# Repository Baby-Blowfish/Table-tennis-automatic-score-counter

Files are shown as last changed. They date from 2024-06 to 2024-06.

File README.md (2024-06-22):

# Table-tennis-automatic-score-counter (2022.06 ~ 2023.12)

## 1. 개발 배경 및 목적 :
    - 지역사회의 스포츠 활성화를 위해 체육학과 학우들과 탁구장을 창업 및 무인으로 탁구장을 운영할 수 있는 탁구자동점수계수 시스템을 구축

## 2. 프로젝트 개요 :

    - 안동형 일자리센터에서 창업 첫걸음 지원사업으로 선정되어 1300만 원을 지원받아 Lead All 탁구장 창업 및 1년간 운영
    - 자동점수 계수기 개발하고 시제품을 1년간 탁구장 배치하여 소비자들의 피드백을 바탕으로 특허 출원
    - 학생 창업 유망팀 300 경진대회 성장 트랙에서 "3차원 동작분석을 통한 탁구선수 경기력 향상 솔루션"으로 모의 투자 대회에서
    2300만원 투자 유치 달성 및 교육부장관 인증서 수상

## 3. 프로젝트 내 역할 
    - 경기자가 PLAYER BOARD의 UP & DOWN 스위치를 조작하여 Bluetooth 통신으로 SCORE BOARD에 점수 제어값을 송신하
    는 기능 개발
    - SCORE BOARD는 PLAYER BOARD의 제어값을 수신받아 점수를 계수하고 결과를 7-segment로 표시하는 기능 개발
    - 스피커로 경기 결과 및 타이머로 경과된 시간을 출력하여 소비자에게 지불할 금액 알림 기능 개발
    - SCORE BOARD에 스마트폰 거치대와 USB-C 타입 충전 기능 개발
    - Kinect camera와 motion capture 기능으로탁구선수의 경기력 향상을 위한 3차원 동작 분석 시스템 설계

## 4. 성과
    - 안동시 창업 첫걸음 사업 (탁구 자동점수 계수기 개발 및 특허 출원), 학생 창업 유망팀 300 경진대회 성장 트랙

##

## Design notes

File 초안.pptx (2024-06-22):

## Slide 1

| 시스템 구성도

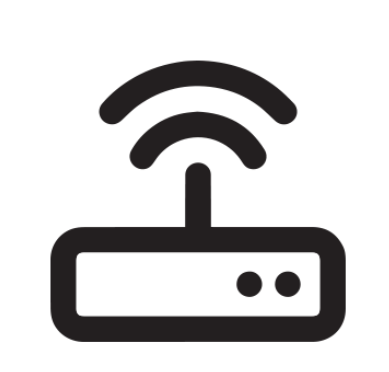
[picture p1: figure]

SCORE BOARD

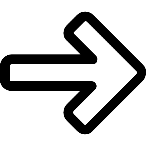
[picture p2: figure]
오른쪽 화살표 무료 아이콘
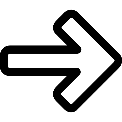
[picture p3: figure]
오른쪽 화살표 무료 아이콘

PLAYER BOARD

PLAYER BOARD

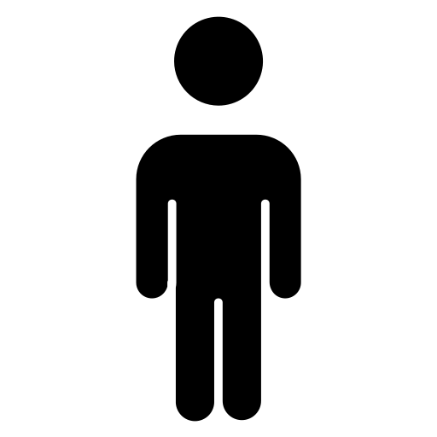
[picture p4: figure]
Man free icon
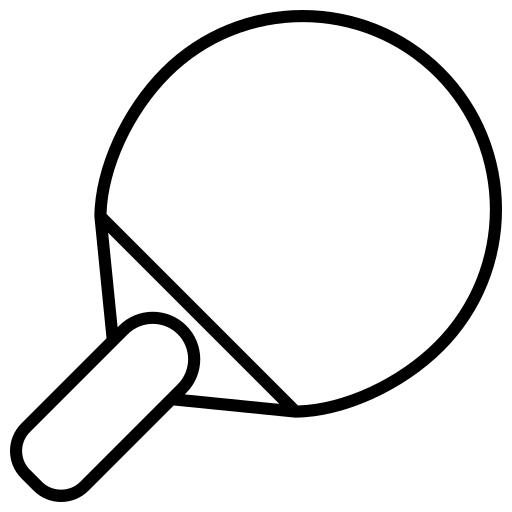
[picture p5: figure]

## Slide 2

| 시스템 구성도

PLAYER BOARD

점수 UP/DOWN 스위치 4개
RESET 스위치 1개
타이머 시작/정지/리셋 스위치 1개

적외선 수신부

점수 7-segment 4개
세트 7-segment 4개
타이머 7-segment 4개

SCORE BOARD

SCORE BOARD

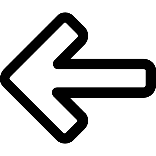
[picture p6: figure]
오른쪽 화살표 무료 아이콘

적외선 통신

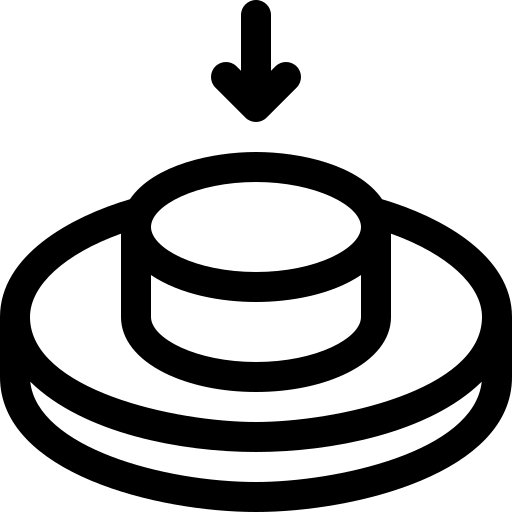
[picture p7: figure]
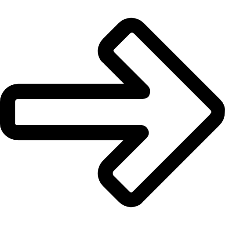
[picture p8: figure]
오른쪽 화살표 무료 아이콘

PHONE CHARGE

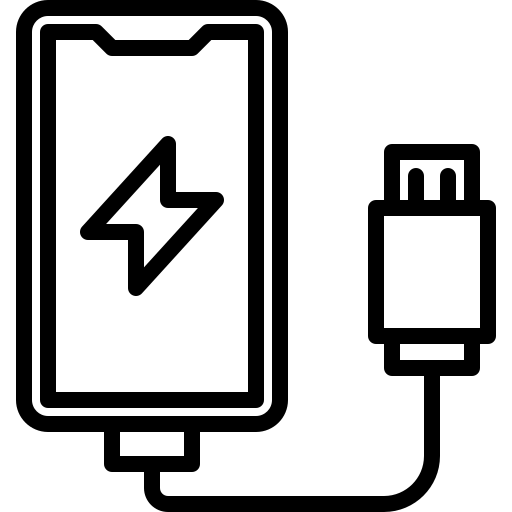
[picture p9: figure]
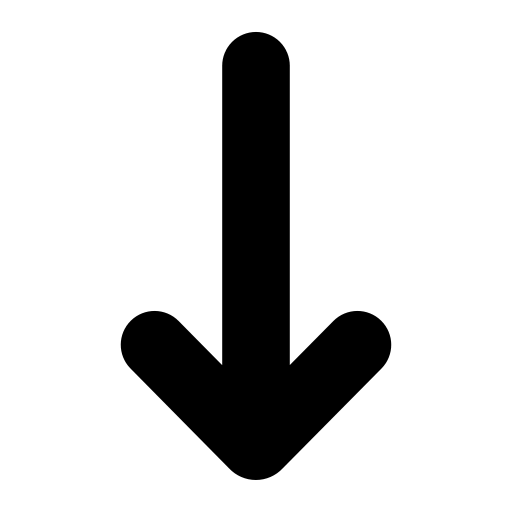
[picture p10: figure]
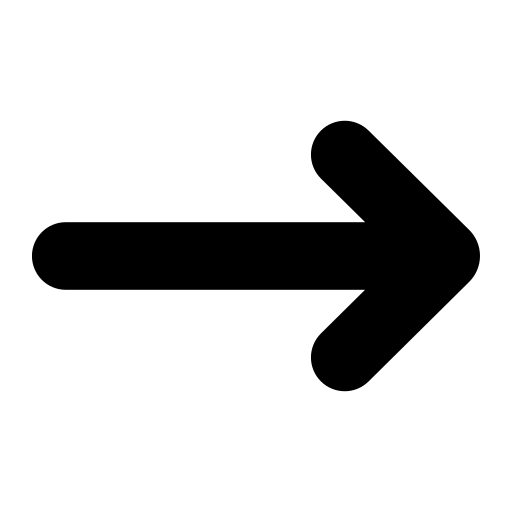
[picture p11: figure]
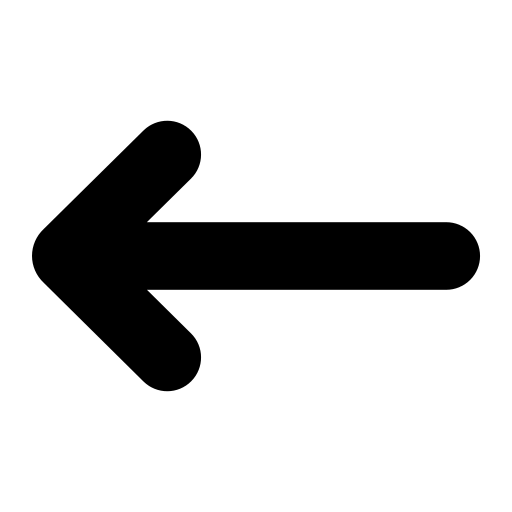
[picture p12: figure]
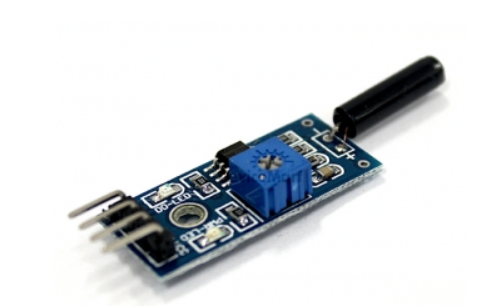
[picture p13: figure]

진동센서 모듈

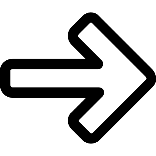
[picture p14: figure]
오른쪽 화살표 무료 아이콘
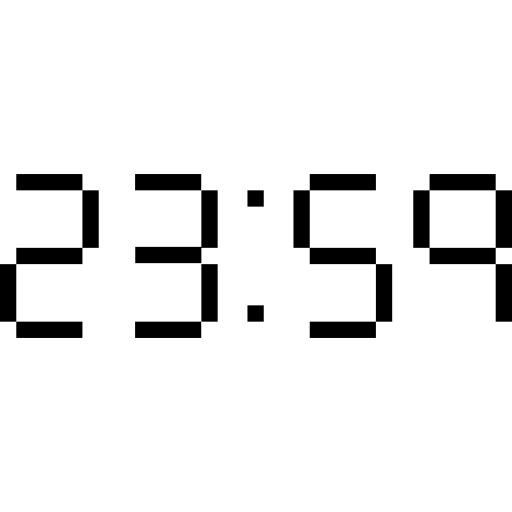
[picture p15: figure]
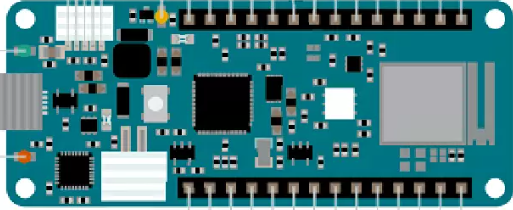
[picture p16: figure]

무선인터넷을 이용해 서버에 데이터 전송

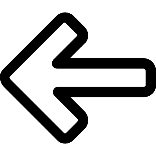
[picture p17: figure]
오른쪽 화살표 무료 아이콘
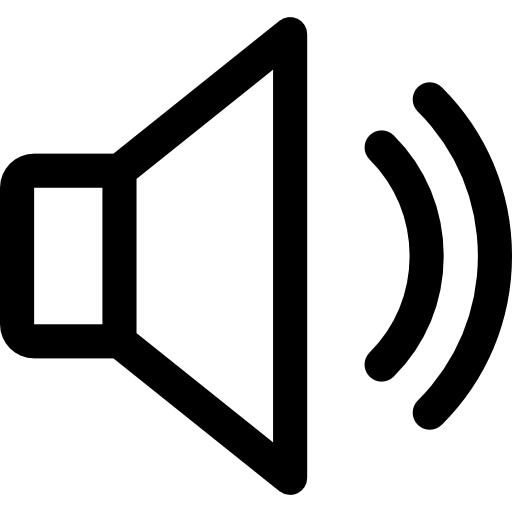
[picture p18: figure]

스피커

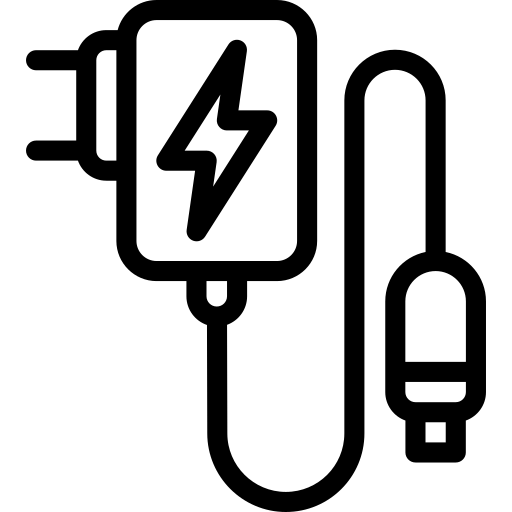
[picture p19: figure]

220V 충전기

MKR wifi 1010

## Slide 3

| 시스템 구성도

PLAYER BOARD

점수 UP/DOWN 스위치 2개

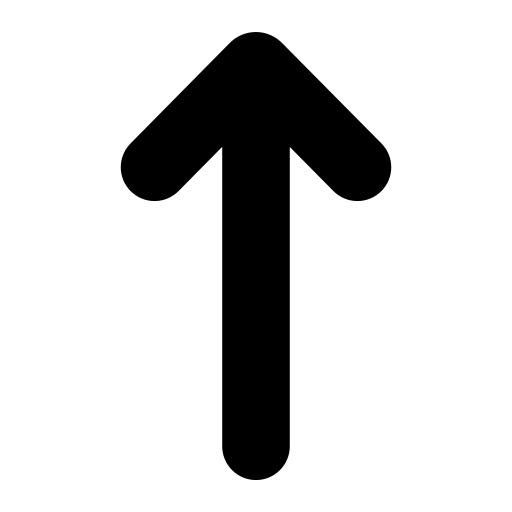
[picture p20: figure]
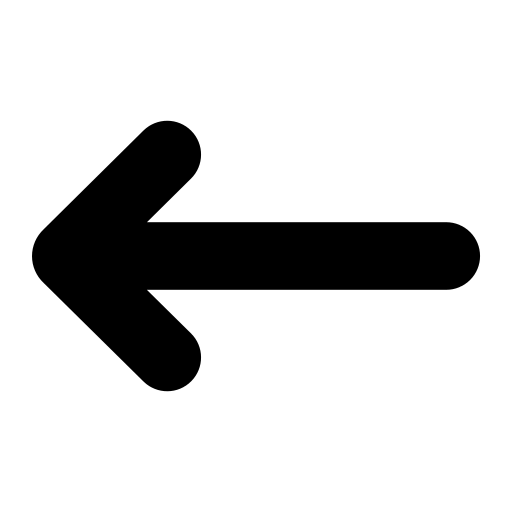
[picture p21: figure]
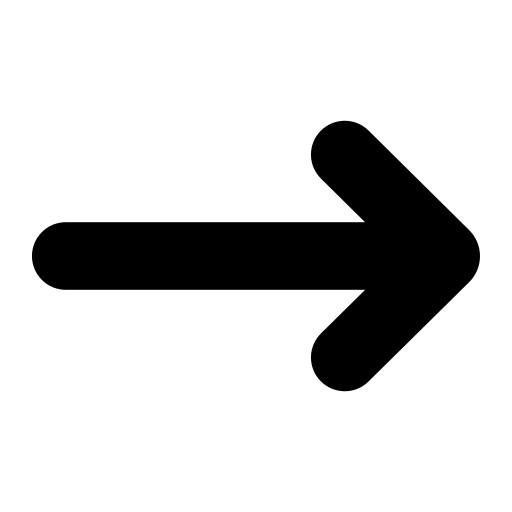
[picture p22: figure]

적외선 송신부

SCORE BOARD

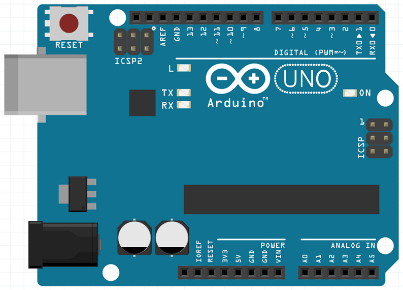
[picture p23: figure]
Arduino 시작하기 | STEM with

Arduino UNO

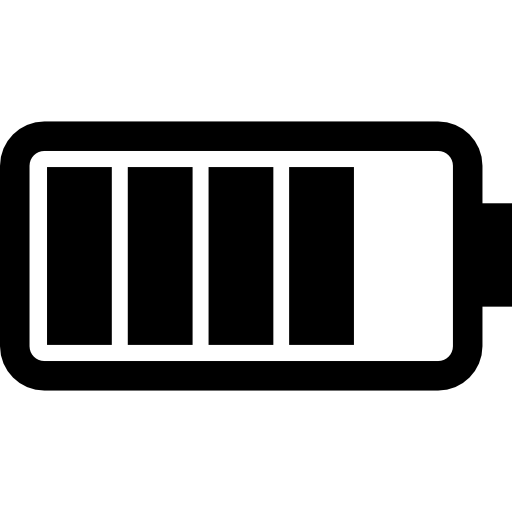
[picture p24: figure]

9V 건전지

적외선 통신

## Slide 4

| SCORE BOARD 전면

세트 스코어 출력
숫자 전광판

점수초기화 버튼

점수 추가/제거 버튼

시간 시작/정지/리셋 버튼

시간 숫자 전광판

점수 출력 숫자 전광판

적외선 송신부

스피커

휴대폰 거치대 및 충전용 USB 단자

음량 조절 단자

진동 센서 연결 포트

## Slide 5

| SCORE BOARD 측면

여닫을 수 있는 거치대

전원 공급 DC 잭 단자

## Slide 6

| PLEAER BOARD 하면/측면

점수 추가/제거 버튼

부착용 벨크로

건전지 교체 뚜껑

적외선 수신부

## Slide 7

| FND PCB

FND 큰거 작은거를 둘 다 호환 가능.
홀더는 설명을 위해 넣음. 실제로는 바로 납땜할거임.
ICD 케이블 홀더를 먼저 납땜 후 PCB를 납땜해야 함.

FND 홀

FND 큰거

FND 작은거

앞

옆

뒤

PCB 고정용
홀, 3파이

10핀 ICD 케이블 홀더

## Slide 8

| MAIN PCB

MAIN PCB
가로 : 260
세로 : 85

sw 8핀 커넥터

dfplayer
mini

가로로
타이머, 스피커,
USB 2개, IR센서
진동센서
5V pin

FND PCB
가로 : 40
세로 : 163

만능기판
12 * 25

SCORE_LEFT

아두이노
MKR 1010 wifi

SET_LEFT

전원
커넥터

SET_RIGHT

SCORE_RIGHT

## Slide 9

| 전체 PCB

FND 큰거 작은거를 둘 다 호환 가능.

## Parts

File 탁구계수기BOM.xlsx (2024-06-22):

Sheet: 경대 BOM
순번 | 이름 | 모델 | 수량 | 규격 | 참고 | 비고
1 | IC | NE555P | 2 | DIP8 | https://www.devicemart.co.kr/goods/view?no=1058745
2 |  | HEF4518BP | 1 | DIP16 | https://www.devicemart.co.kr/goods/view?no=1056986
3 |  | MC14051B | 2 | SO16 | https://www.devicemart.co.kr/goods/view?no=1056791
4 |  | LM324N | 1 | DIP14 | https://www.devicemart.co.kr/goods/view?no=1056784
5 |  | HEF4027BT | 1 | SO16 | https://www.devicemart.co.kr/goods/view?no=1056677
6 |  | MC14175BDR2G | 1 | SO16
7 |  | CD74HC123E | 1 | DIP16 | https://www.ti.com/lit/ds/symlink/cd74hc123.pdf
8 |  | LM7805C | 1 | TO-220
9 |  | LM7905C | 1 | TO-220
10 |  | HEF4049BT | 2 | SO16 | https://www.devicemart.co.kr/goods/view?no=14811357
11 |  | HEF4081BT | 1 | SO14 | https://www.devicemart.co.kr/goods/view?no=14566419
12 |  | HEF4011BT | 1 | SO14 | https://www.devicemart.co.kr/goods/view?no=14811434
13 |  | CD4012BE | 1 | DIP14 | https://www.devicemart.co.kr/goods/view?no=12430497
14 |  | MC14024BDG | 1 | SO14 | https://www.devicemart.co.kr/goods/view?no=14811451
15 |  | CD74HC192E | 4 | DIP16 | https://www.devicemart.co.kr/goods/view?no=14623818
16 |  | SN74LS47N | 4 | DIP16 | https://www.devicemart.co.kr/goods/view?no=28231
17 | 다이오드 | 1N5819 | 5 |  | https://www.devicemart.co.kr/goods/view?no=6514584
18 | 저항 |  |  | 칩 1608 |  | DIP도 상관없음
19 | 세라믹 콘덴서 |  |  | 칩 1608 |  | DIP도 상관없음
20 | 전해 콘덴서 |  |  | DIP
21 | 가변 저항 |  | 7 | 3296W(일자 3홀)
22 | 부저 | SM-1205C | 1 | DIP | https://www.devicemart.co.kr/goods/view?no=2736
23 | 트렌지스터 | 2n2222 | 2 | DIP
24 | 전원 | [MOLEX] 5267-03 | 1 | DIP3 | https://www.devicemart.co.kr/goods/view?no=418
25 | 서보 모터 헤더 | pin header | 1 | DIP3
26 | 서보 모터 | HS-311
27 | 7-segment | 5101ASR | 4 | DIP | https://www.devicemart.co.kr/goods/view?no=11551
28 | 텍트 스위치 |  | 1 | DIP | https://www.devicemart.co.kr/goods/view?no=1361702
29 | 4p 슬라이트 스위치 | KSD04S | 2 | 4PIN SMD | https://www.devicemart.co.kr/goods/view?no=31631

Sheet: 경대 창의회로설계 사용 IC
이름 | 제조사 | 타입 | 설명
HEF4518BP | NXP | DIP16 | Dual BCD counter
HEF4520BT | NXP | SO16 | Dual binary counter
DAC0800LCN | national semiconductor | DIP16 | 8-Bit D/A Converters | https://pdf1.alldatasheet.co.kr/datasheet-pdf/view/8300/NSC/DAC0800LCN.html
MC14543BCPG | on semi | DIP16 | BCD-to-Seven Segment Latch/Decoder/Driver for liquit crystals | https://pdf1.alldatasheet.com/datasheet-pdf/view/174233/ONSEMI/MC14543BCPG.html
MC14051B | on semi | so16 | Analog Multiplexers/Demultiplexers | pspice에서 대신 10164 사용
HEF4027BT | PHILIPS | so16 | Dual JK flip-flop | https://pdf1.alldatasheet.com/datasheet-pdf/view/17706/PHILIPS/4027.html
MC14175BDR2G | on semi | SO16 | quad type d flip-flop
74HC257D |  | SO16 | Quad 2-input multiplexer
CD74HC123E | texas instruments |  | High-Speed CMOS Logic Dual Retriggerable Monostable Multivibrators with Resets Retrigger 가능 단안정 멀티바이브레이터 | https://www.ti.com/lit/ds/symlink/cd74hc123.pdf
74LS193 |  | DIP16 | presettable BCD up/down counter | https://pdf1.alldatasheet.com/datasheet-pdf/view/5680/MOTOROLA/74LS193.html https://pdf1.alldatasheet.com/datasheet-pdf/view/51049/FAIRCHILD/74LS193.html
 |  |  |  |  |  | [표 3-23] 디멀티플렉서의 진리표
 |  |  |  |  |  | 순서 | 선택 |  | 입력 | 출력
 |  |  | cds센서는 70~5M 옴 정도가 나옴 |  |  |  | S1 | S0 | I | Y3 | Y2 | Y1 | Y0
 |  |  | 평소에는 10K옴, 적당히 어두우면 100k옴 |  |  | 1 | 0 | 0 | 1 | 0 | 0 | 0 | 1
 | 비안정 NE555 계산기 |  |  |  |  | 2 | 0 | 0 | 0 | 0 | 0 | 0 | 0
 | R1(위) | R2(아래) | C1 |  |  | 3 | 0 | 1 | 1 | 0 | 0 | 1 | 0
 | 22000 | 3400 | 1e-07 |  |  | 4 | 0 | 1 | 0 | 0 | 0 | 0 | 0
 | t H | 0.00176022 |  |  | 방법 2 | 5 | 1 | 0 | 1 | 0 | 1 | 0 | 0
 | t L | 0.00023562 |  |  |  | 6 | 1 | 0 | 0 | 0 | 0 | 0 | 0
 | period | 0.00199584 |  |  |  | 7 | 1 | 1 | 1 | 1 | 0 | 0 | 0
 | frequency | 501.0421677 |  |  |  | 8 | 1 | 1 | 0 | 0 | 0 | 0 | 0
 | 비안정 NE555 계산
 | R1(위) | R2(아래) | C1
 | 370000 | 400 | 0.00022
 | t H | 56.471184
 | t L | 0.060984
 | period | 56.532168 | 초
 | frequency | 0.01768904387
 | CD4024 출력
 | 분주비 64 | 60.3009792 | 분
 | 단안정 NE555 계산기
 | R | C
 | 21000 | 1e-07
 | t H | 0.00231
 | 74HC123 계산기
 | 콘덴서 | 저항1
 | 1e-07 | 55000
 | pulse 길이 | 0.002475
 | 콘덴서 | 저항2
 | 1e-07 | 43000
 | pulse 길이 | 0.001935
 | 콘덴서 | 저항3
 | 1e-07 | 34000
 | pulse 길이 | 0.00153
 | 콘덴서 | 저항4
 | 1e-07 | 25000
 | pulse 길이 | 0.001125
 | 콘덴서 | 저항5
 | 1e-07 | 16000
 | pulse 길이 | 0.00072

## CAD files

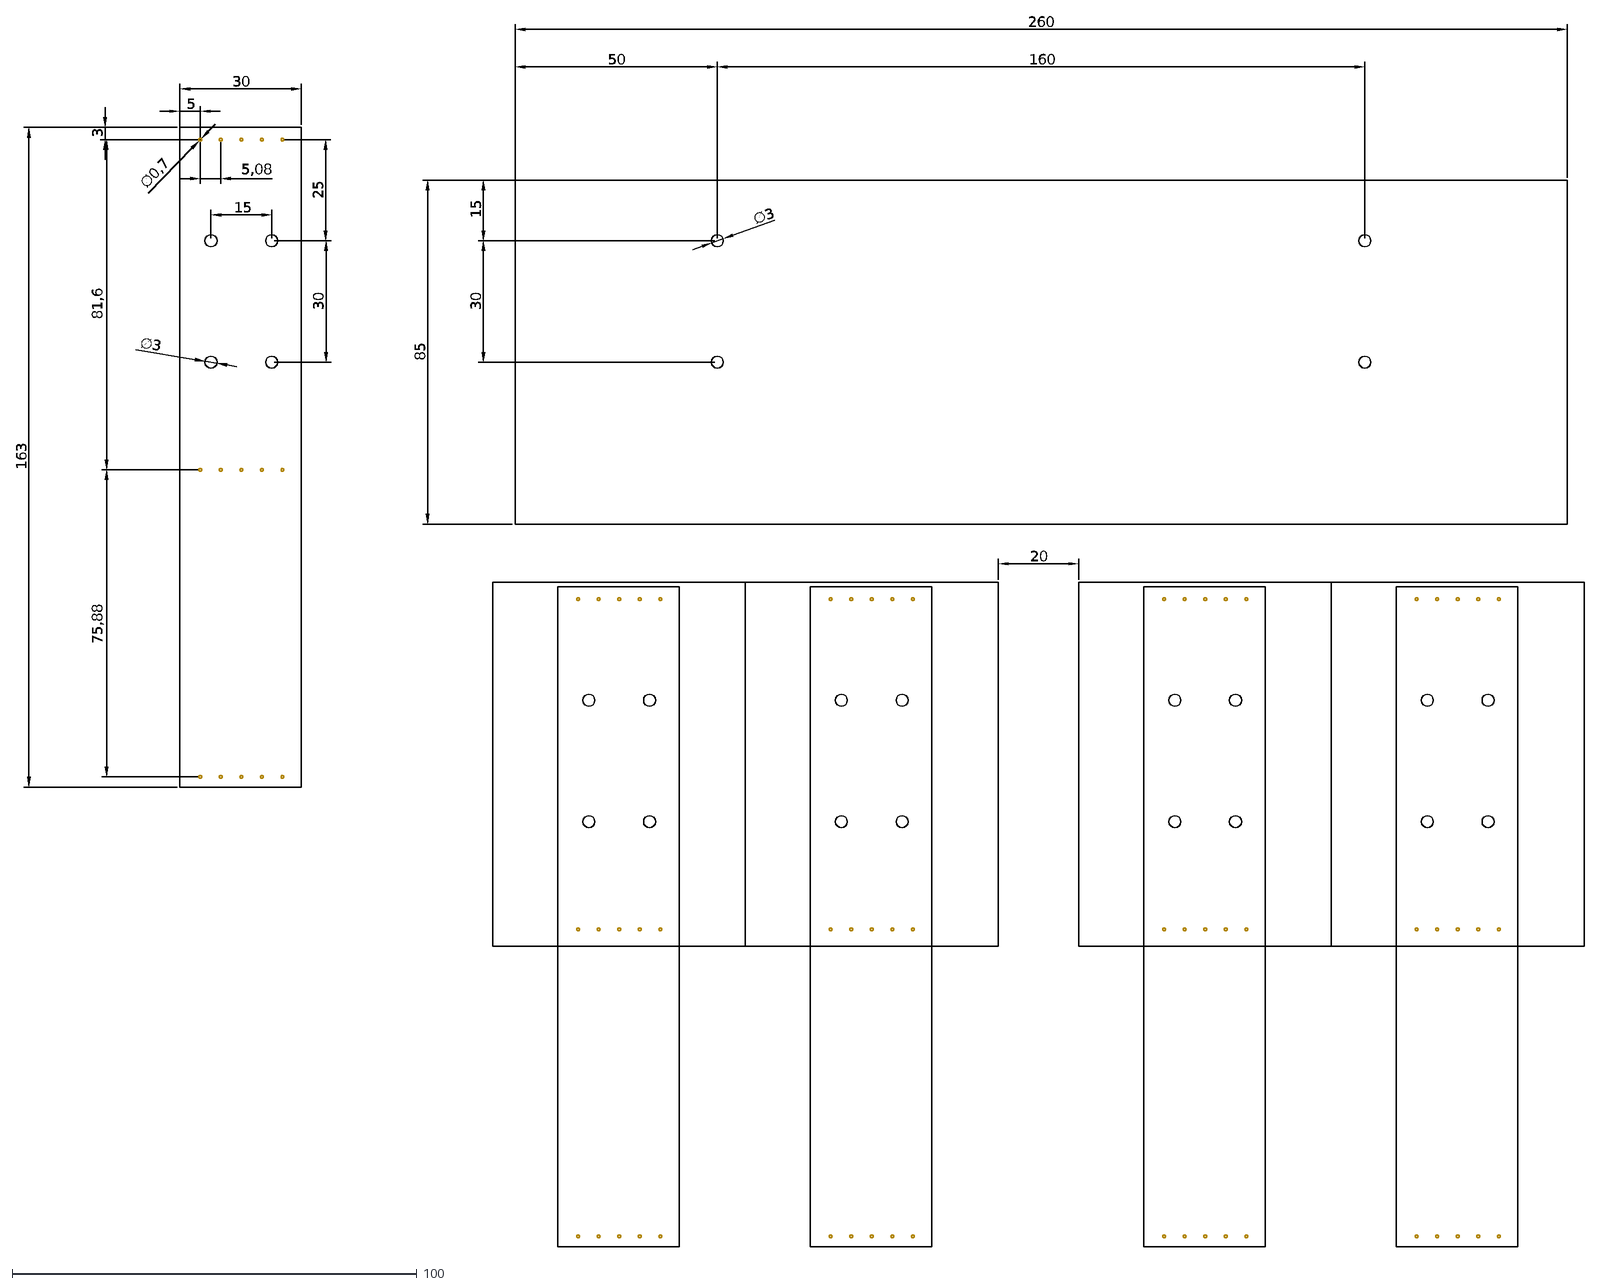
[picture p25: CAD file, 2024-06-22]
ping_pong.dxf
30
5
∅0,7
5,08
81,6
75,88
3
15
25
∅3
20
160
50
163
260
85

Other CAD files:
ping_pong.dwg

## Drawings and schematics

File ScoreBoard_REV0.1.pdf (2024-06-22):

D

6 | 5 | 4 | 3 | 2 | 1

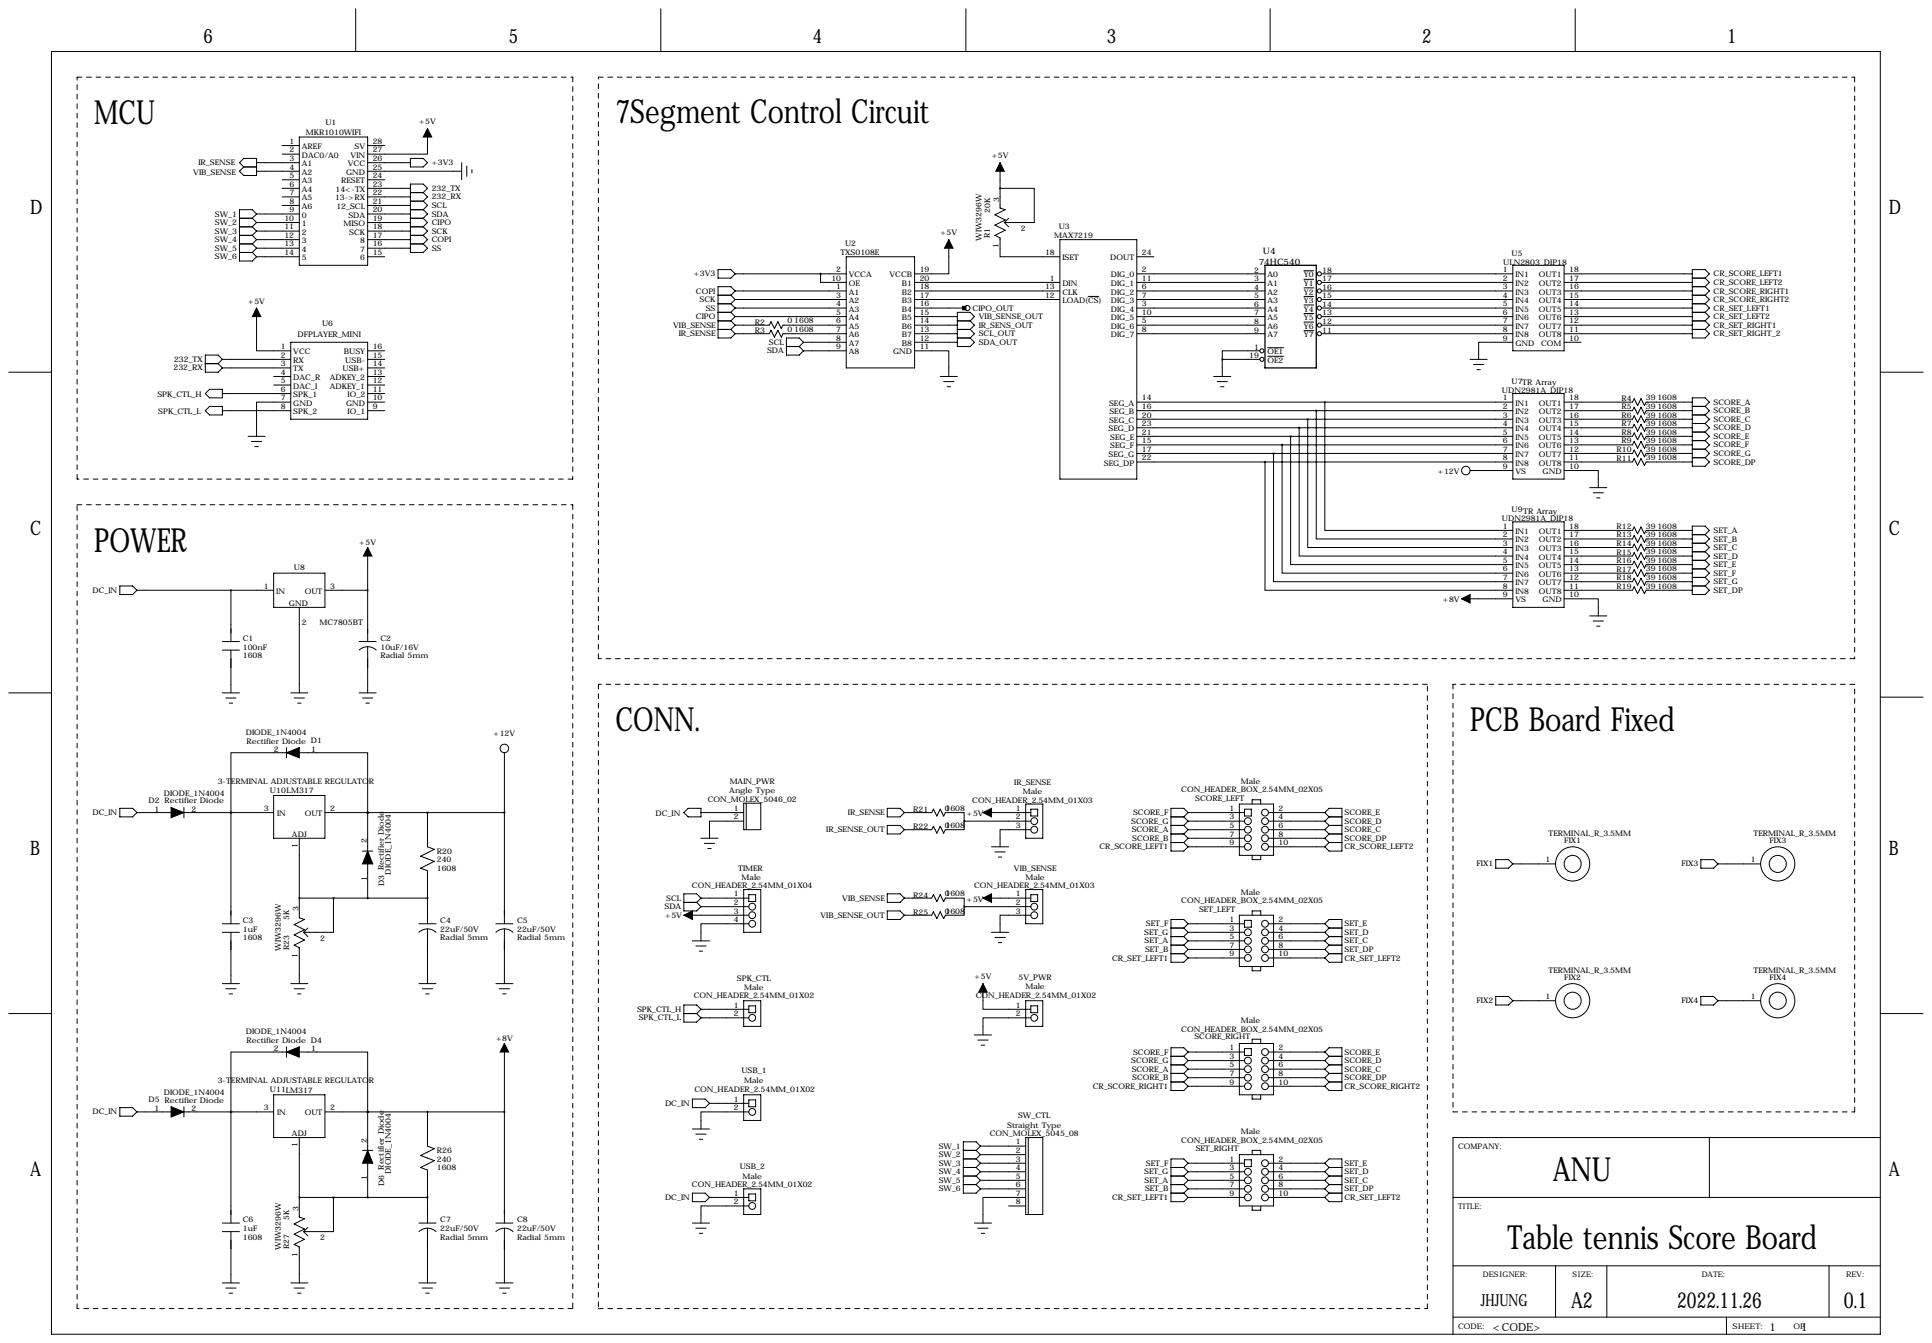
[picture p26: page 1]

COMPANY:
ANU
Table tennis Score Board

DESIGNER: JHJUNG | SIZE: A2 | DATE: 2022.11.26 | REV: 0.1

CODE: <CODE> | SHEET: 1 OF 1

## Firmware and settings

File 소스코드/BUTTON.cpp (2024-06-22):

#include <TM1637Display.h>
#include <IRremote.h>
#include "LedControl.h"
#include <SoftwareSerial.h>
#include <DFRobotDFPlayerMini.h>
#include "Arduino.h"
//#define SUPPRESS_ERROR_MESSAGE_FOR_BEGIN
#define FND_DIO 9
#define FND_CLK 8
#define FND_CS 7
#define RED_UP_switch 58
#define RED_DOWN_switch 59
#define timer_switch 56
#define set_reset_switch 57
#define BLUE_UP_switch 54
#define BLUE_DOWN_switch 55
#define IR_RECEIVE_PIN 5
#define timer_CLK 4
#define timer_DIO 3

int RED_score =0;
int RED_set =0;
int BLUE_score =0;
int BLUE_set =0;

//IRrecv irrecv(IR_RECEIVE_PIN);             //적외선 수신용
//decode_results results;

LedControl lc = LedControl(FND_DIO, FND_CLK, FND_CS, 1);    //MOSI, CLK, CS   선언

SoftwareSerial mySoftwareSerial(10, 11); // RX, TX
DFRobotDFPlayerMini myDFPlayer;
void printDetail(uint8_t type, int value);

TM1637Display display(timer_CLK, timer_DIO);

extern volatile unsigned long timer0_millis;  //millis 함수 초기화변수
unsigned long timeLimit = 3600000;// 1000*60*30 = 60분
int hour, minu, sec;
unsigned long readTime; //timer출력용 시간
unsigned long timeVal=0;//이전시간
int cnt = 0;
int Flag =0;
int counts =0;
unsigned long cnts = 0; //버튼눌리는 시간의 거리
int states = 0;
char turnon='0';
char check='0';


// 스위치 디바운싱
long BLUE_UP_DebounceTime=0;
long BLUE_DOWN_DebounceTime=0;
long RED_UP_DebounceTime=0;
long RED_DOWN_DebounceTime=0;
long set_reset_switch_DebounceTime=0;
long debounceDelay=20;
int state[5]={0,};
int laststate[5]={0,};
int Button[5]={0,};



void timer(int readTime){           //타이머 출력
  sec = readTime%60;
  minu = (readTime/60)%60;
  hour = (readTime/(60*60))%24;

   if (sec == 5)                    //시간 출력부분인듯 하니, 변수를 minu나 hour로 바꾸면 분,시간마다 출력이 가능할듯함.
  {
    myDFPlayer.play(1);
    if (myDFPlayer.available()) {
      printDetail(myDFPlayer.readType(), myDFPlayer.read());
    }
  }

  else if (sec == 10)
  {
    myDFPlayer.play(2);
    if (myDFPlayer.available()) {
      printDetail(myDFPlayer.readType(), myDFPlayer.read());
    }
  }

  else if (sec == 15)
  {
    myDFPlayer.play(3);
    if (myDFPlayer.available()) {
      printDetail(myDFPlayer.readType(), myDFPlayer.read());
    }
  }

  else if (sec == 20)
  {
    myDFPlayer.play(4);
    if (myDFPlayer.available()) {
      printDetail(myDFPlayer.readType(), myDFPlayer.read());
    }
  }

  else if (sec == 25)
  {
    myDFPlayer.play(5);
    if (myDFPlayer.available()) {
      printDetail(myDFPlayer.readType(), myDFPlayer.read());
    }
  }

  else if (sec == 30)
  {
    myDFPlayer.play(6);
    if (myDFPlayer.available()) {
      printDetail(myDFPlayer.readType(), myDFPlayer.read());
    }
  }
  //display.showNumverDecEx(x,0,ture,2,2) x부분이 실제 출력 부분! 
  //x자리에 초를 표시하고 싶으면 sec대입, 분을 대입하고싶으면 minu대입, 시간을 대입하고싶으면 hour대입!
  display.showNumberDecEx(minu, 0, true,2,2) ;                 
  display.showNumberDecEx(hour, (0x80 >> 1), false, 2, 0) ;  // turn on colon    원본은  0x80 >> 3 인데 콜론이 on 되지 않아 0x80 >> 1 로 변경
}                              //숫자와 숫자사이 :표시 >> (0x80>>1)

void FND_display(){         //점수, 세트 스코어 출력
  if(BLUE_score<0) BLUE_score=0;
  if(BLUE_set<0) BLUE_set=0;
  if(RED_score<0) RED_score=0;
  if(RED_set<0) RED_set=0;  

  lc.clearDisplay(0);
  lc.setDigit(0,7,BLUE_set/10, false); // 
  lc.setDigit(0,6,BLUE_set%10, false); // 
  lc.setDigit(0,5,RED_set/10, false); //
  lc.setDigit(0,4,RED_set%10, false); // 

  lc.setDigit(0,3,BLUE_score/10, false); // 
  lc.setDigit(0,2,BLUE_score%10, false); // 
  lc.setDigit(0,1,RED_score/10, false); // 
  lc.setDigit(0,0,RED_score%10, false); // 

}

void SW_Score(int sw_name, int num, long DebounceTime, int *score, int i) // i=1이면 업카운트 아니면 다운 카운트
{
  state[num]=digitalRead(sw_name);
  //점수 
  if(state[num]!=laststate[num]){
    DebounceTime=millis();
  }
  if((millis()-DebounceTime)>debounceDelay)
  {
    if(state[num]!=Button[num])
    {
      Button[num]=state[num];
      
      if(Button[num]==HIGH)
      {
        if(i>=1)
        {
          ++*score;
          FND_display();
        }
        else
        {
          --*score;
          FND_display();
        }
       
      }
    }
  }
  laststate[num]=state[num];
}

void setup() {
  mySoftwareSerial.begin(9600);
  Serial.begin(9600);
  display.setBrightness(7);
  display.showNumberDecEx(0, 0x40, true);    //64
  IrReceiver.enableIRIn();//적외선 수신on
  lc.shutdown(0, false);  // 도트매트릭스의 절전모드를 꺼줍니다.
  lc.setIntensity(0, 15);  // 도트매트릭스의 LED 밝기를 8로 지정해 줍니다.(0~15)
  lc.clearDisplay(0);     // 도트매트릭스의 LED를 초기화 해줍니다.

  pinMode(timer_switch,INPUT_PULLUP);
  pinMode(set_reset_switch,INPUT_PULLUP);
  pinMode(RED_UP_switch,INPUT_PULLUP);
  pinMode(RED_DOWN_switch,INPUT_PULLUP);
  pinMode(BLUE_UP_switch,INPUT_PULLUP);
  pinMode(BLUE_DOWN_switch,INPUT_PULLUP);
  FND_display();

  Serial.println();
  Serial.println(F("DFRobot DFPlayer Mini Demo"));
  Serial.println(F("Initializing DFPlayer ... (May take 3~5 seconds)"));

  if (!myDFPlayer.begin(mySoftwareSerial)) {  //Use softwareSerial to communicate with mp3.
    Serial.println(F("Unable to begin:"));
    Serial.println(F("1.Please recheck the connection!"));
    Serial.println(F("2.Please insert the SD card!"));
    while (true);
  }
  Serial.println(F("DFPlayer Mini online."));
  IrReceiver.begin(IR_RECEIVE_PIN, ENABLE_LED_FEEDBACK);
  myDFPlayer.volume(30);  //Set volume value. From 0 to 30
}

void loop() 
{
  // score count
  SW_Score(BLUE_UP_switch,0,BLUE_UP_DebounceTime,&BLUE_score,1); 
  SW_Score(BLUE_DOWN_switch,1,BLUE_DOWN_DebounceTime,&BLUE_score,0);
  SW_Score(RED_UP_switch,2,RED_UP_DebounceTime,&RED_score,1);
  SW_Score(RED_DOWN_switch,3,RED_DOWN_DebounceTime,&RED_score,0);
  
  // IR score count
  if(IrReceiver.decode()){ // 적외선 수신 받으면
   Serial.println(IrReceiver.decodedIRData.decodedRawData,HEX);//시리얼로 적외선 신호값 출력
  
  switch(IrReceiver.decodedIRData.decodedRawData)
    {
      case 0xD02F8778: ++BLUE_score;break;    //청팀UP버튼 받았을때. 
      case 0xDF028778: --BLUE_score;break;     //청팀DOWN버튼 받았을때.
      case 0xD02F47F8: ++RED_score;break;    //홍팀UP버튼 받았을때.
      case 0xDF0247B8: --RED_score;break;     //홍팀DOWN버튼 받았을때.
      case 0x1EE150FB: Serial.println("net");break;
      default: break;
    }
  IrReceiver.resume();
  FND_display();  
  }

  // score set count
  if(RED_score>10||BLUE_score>10){ 
    if((RED_score-BLUE_score)>=2){
      ++RED_set;
      RED_score=0;      
      BLUE_score=0;
      FND_display();   
      //스피커출력
    }
    else if((BLUE_score-RED_score)>=2){
      ++BLUE_set;
      RED_score=0;      
      BLUE_score=0;
      FND_display();      
      //스피커출력
    }    
  }

  // score reset
  if(digitalRead(set_reset_switch)==LOW)
  {
    RED_score =0;
    RED_set =0;
    BLUE_score =0;
    BLUE_set =0;
    FND_display();
  }


  //timer 정지, 리셋
  if((digitalRead(timer_switch)==LOW)&&counts==0&&cnts==0){//버튼을 눌리면
    while(digitalRead(timer_switch)==LOW);
    cnts = millis();//현재시간
    counts++;       //누른 횟수
  }
  else if(millis() >cnts+1000&&cnts>0){//1초안에 버튼을 누르지 않고 1번이상 눌렀을때
    states = counts;  //누른 횟수 저장
    counts = 0;     //카운트 초기화
    cnts = 0;       //초기화 
    if(Flag==0)Flag=1;
    else if(Flag==1)Flag=0;
  }
  else if((digitalRead(timer_switch)==LOW)&&millis()<cnts+300){//0.5초안에 한번더 눌리면
    while(digitalRead(timer_switch)==LOW);
    cnts=millis();//시간 초기화
    counts++;     //카운트 증가
    if(counts>=2)counts=2; //3번이상이면 카운트 3 

  }
  switch(states){
    case 0:
      break;
    case 1:       //시작, 일시정지
      if(Flag==0)timer(cnt);
      else if(Flag==1){
        Serial.println(millis() - timeVal);
        if(millis()-timeVal>=1000){
          timeVal = millis();
          cnt++;
        }
        timer(cnt);
      }
    break;
    case 2:        //초기화
      cnt=0;
      states=1;
      Flag=0;
    break;
  }
}


void printDetail(uint8_t type, int value) {
  switch (type) {
    case TimeOut:
      Serial.println(F("Time Out!"));
      break;
    case WrongStack:
      Serial.println(F("Stack Wrong!"));
      break;
    case DFPlayerCardInserted:
      Serial.println(F("Card Inserted!"));
      break;
    case DFPlayerCardRemoved:
      Serial.println(F("Card Removed!"));
      break;
    case DFPlayerCardOnline:
      Serial.println(F("Card Online!"));
      break;
    case DFPlayerPlayFinished:
      Serial.print(F("Number:"));
      Serial.print(value);
      Serial.println(F(" Play Finished!"));
      break;
    case DFPlayerError:
      Serial.print(F("DFPlayerError:"));
      switch (value) {
        case Busy:
          Serial.println(F("Card not found"));
          break;
        case Sleeping:
          Serial.println(F("Sleeping"));
          break;
        case SerialWrongStack:
          Serial.println(F("Get Wrong Stack"));
          break;
        case CheckSumNotMatch:
          Serial.println(F("Check Sum Not Match"));
          break;
        case FileIndexOut:
          Serial.println(F("File Index Out of Bound"));
          break;
        case FileMismatch:
          Serial.println(F("Cannot Find File"));
          break;
        case Advertise:
          Serial.println(F("In Advertise"));
          break;
        default:
          break;
      }
      break;
    default:
      break;
  }
}

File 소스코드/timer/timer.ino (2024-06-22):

#include <TM1637Display.h>
#include <IRremote.h>
#define CLK 8
#define DIO 9
#define SW 4

TM1637Display display(CLK, DIO);
IRrecv irrecv(7);             //적외선 수신용

extern volatile unsigned long timer0_millis;  //millis 함수 초기화변수
unsigned long timeLimit = 3600000;// 1000*60*30 = 60분
int hour, minu, sec;
unsigned long readTime; //FND출력용 시간
unsigned long timeVal=0;//이전시간
int cnt = 0;
int Flag =0;
int counts =0;
unsigned long cnts = 0; //버튼눌리는 시간의 거리
int states = 0;
char turnon='0';
char check='0';
void fnd(int readTime)
{
  sec = readTime%60;
  minu = (readTime/60)%60;
  hour = (readTime/(60*60))%24;
  /*Serial.print(hour);
  Serial.print(":");
  Serial.print(minu);
  Serial.print(":");
  Serial.print(sec);
  Serial.println('\n');*/
  /* As per most tasks, this task is implemented in an infinite loop. */
    display.showNumberDecEx(sec, 0, true,2,2) ;
    // Display the minutes in the first two places, with colon
    display.showNumberDecEx(minu, (0x80 >> 1), false, 2, 0) ;  // turn on colon    원본은  0x80 >> 3 인데 콜론이 on 되지 않아 0x80 >> 1 로 변경
    //showNumberDecEx(표시할번호,도트,선행제로,설정할 자릿수,위치 최하위 숫자(0-맨왼쪽 ,3맨오른쪽)); 
    /*도트
    00:00 (0b01000000) 점과 콜론 콜론이있는 디스플레이의 경우 :
   */ 
}
void setup() {
  Serial.begin(9600);
  display.setBrightness(7);
  pinMode(SW,INPUT_PULLUP);
  display.showNumberDecEx(0, 0x40, true);    //64
  irrecv.enableIRIn();//적외선 수신on
}

void loop() {
  /*if(irrecv.decode(&results))//적외선 수신을 받으면
  {
    Serial.println(results.value,HEX);//시리얼로 적외선 신호값 출력
    switch(results.value)
    {
      case 0x1EE1F40B: digitalWrite(6,HIGH);break;    //청팀UP버튼 받았을때.>>처리할 문장 입력하면 됨.  
      case 0x1EE140FB: digitalWrite(6,LOW);break;     //청팀DOWN버튼 받았을때.>>처리할 문장 입력하면 됨.
      case 0x1EE1F40B: digitalWrite(6,HIGH);break;    //홍팀UP버튼 받았을때.>>처리할 문장 입력하면 됨.  
      case 0x1EE140FB: digitalWrite(6,LOW);break;     //홍팀DOWN버튼 받았을때.>>처리할 문장 입력하면 됨.
      default: break;
    }
    irrecv.resume();
  }*/
  if((digitalRead(SW)==LOW)&&counts==0&&cnts==0)//버튼을 눌리면
  {
    while(digitalRead(SW)==LOW);
    cnts = millis();//현재시간
    counts++;       //누른 횟수
    /*Serial.print("states:");
    Serial.print(states);
    Serial.print("counts:");
    Serial.print(counts);
    Serial.print("\n");*/
  }
  else if(millis() >cnts+1000&&cnts>0)//1초안에 버튼을 누르지 않고 1번이상 눌렀을때
  {
    states = counts;  //누른 횟수 저장
    counts = 0;     //카운트 초기화
    cnts = 0;       //초기화 
    Serial.print("states:");
    Serial.print(states);
    Serial.print("counts:");
    Serial.print(counts);
    Serial.print("\n");
    if(Flag==0)Flag=1;
    else if(Flag==1)Flag=0;
  }
  else if((digitalRead(SW)==LOW)&&millis()<cnts+300)//0.5초안에 한번더 눌리면
  {
    while(digitalRead(SW)==LOW);
    cnts=millis();//시간 초기화
    counts++;     //카운트 증가
    if(counts>=2)counts=2; //3번이상이면 카운트 3 
    /*Serial.print("states:");
    Serial.print(states);
    Serial.print("counts:");
    Serial.print(counts);
    Serial.print("\n");*/
  }
  switch(states)
  {
    case 0:
    break;
    case 1:
      if(Flag==0)fnd(cnt);
      else if(Flag==1)
      {
        if(millis()-timeVal>=1000)
        {
          timeVal = millis();
          cnt++;
        }
        fnd(cnt);
      }
    break;
    case 2:
      cnt=0;
      states=1;
      Flag=0;
    break;
  }
}
